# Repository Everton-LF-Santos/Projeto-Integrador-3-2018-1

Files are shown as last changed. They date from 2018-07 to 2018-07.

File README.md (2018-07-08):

<h1> Sistema de aquisição de sinais elétricos musculares microcontrolado </h1>

<p>Repositorio criado para a disciplina de Projeto Integrador 3, do curso de engenharia eletrônica do IFSC - câmpus Florianópolis. <br/>
</p>

<h2> Revisão Bibliográfica </h2>

<p> A revisão bibliográfica pode ser acessada na wiki deste projeto.</p>
<p> A seguir, links de uma apresentação e um relatório técnico elaborados para outra disciplina, mas em cima do mesmo projeto, que podem ajudar na compreensão.<p>

[Apresentação - EMG](https://github.com/Everton-LF-Santos/Projeto-Integrador-3-2018-1/blob/Eletroneuromiografia-ENMG/prototipo_e_testes/Apresenta%C3%A7%C3%A3o%20PI3%20-%20COm.pdf)

[Relatório Técnico -EMG](https://docs.google.com/document/d/1B7dxLtk4YTgo0cG7-Vo4bE_Du3ThqNgDaQOGe45rIPg/edit)

<h2> Diagrama de blocos </h2>

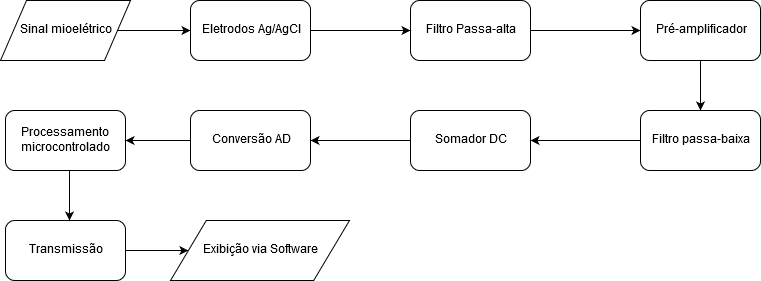
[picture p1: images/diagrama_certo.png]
Figura 1 - Diagrama de blocos do projeto Diagrama de Blocos


<h2> Pré-amplificador e filtro passa-alta </h2>
<p> Com a leitura das referências bilbiográficas da área feita e o diagrama de blocos definido, iniciou-se o desenvolvimento do projeto com o circuito de pré-amplificação. Foi encontrada no livro The Biomedical Engineering Book, uma topologia que junta o pré-amplificador e o filtro passa-alta no mesmo circuito. No exemplo da topologia, coincidentemente foi usado o INA118, mesmo amplificador de instrumentação disponível para o projeto. Na imagem a seguir, temos o esquemático simplificado e definição do ganho do componente.<p>
  
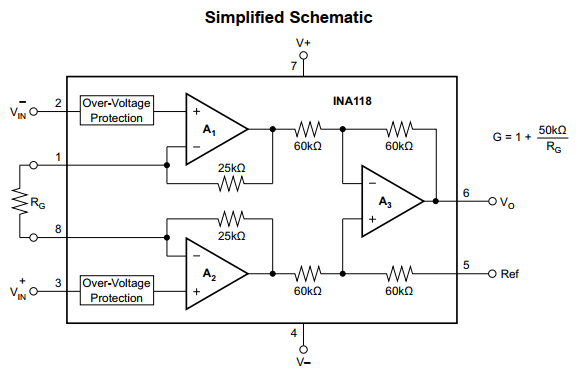
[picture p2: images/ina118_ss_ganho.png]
Figura 2 - esquematico e ganho INA118 Esquemático simples e ganho INA118
 

<p>Foi arbitrado um ganho de 51 para a estrutura, por resultar em um valor de 1kohm para Rg, fácil de obter, e por ser um valor na faixa aceitável de ganho para esse tipo de estrutura neste tipo de aplicação, segundo a bibliografia estudada. A frequência de corte do passa-alta foi definida como 25 Hz, pois abaixo desse valor há ruídos de movimentação mecânica, e os diagramas de energia observados nas referências mostra a concentração de energia do sinal para a faixa acima deste valor.<p>
  
<p>Todas as considerações feitas, os cálculos e simulações pertinentes foram executados. Os arquivos de ambas etapas citadas estão disponível no link.<p>
  
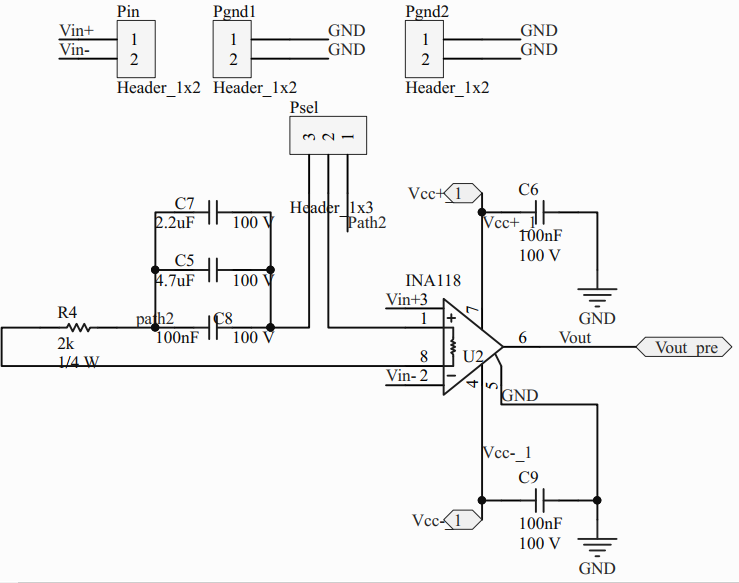
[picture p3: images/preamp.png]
Figura 3 - Circuito projetado Circuito projetado


[Calculos e Simulacoes - Pre_amp e PA](https://github.com/Everton-LF-Santos/Projeto-Integrador-3-2018-1/tree/Eletroneuromiografia-ENMG/pre_amp_e_passa_alta)

<h2> Filtro passa-baixa </h2>

<p>Com o primeiro bloco projetado, passou-se para o próximo bloco, o filtro passa-baixa. A topologia escolhida foi o filtro ativo Multiple Feedback com aproximação Butterworth. O ganho foi escolhido para 12,5 com o intuito de deixar o ganho em cascata da estrutura na casa das unidades de centenas. A frequência de corte de 250 Hz foi escolhida baseada no estudo dos diagramas de frequência do sinal  EMG. O ampop escolhido para implementar o circuito deste bloco foi o LM324, por atender as especificações de ganho e frequência e ser um componente de fácil obtenção e barato. Com os parâmetros do bloco definidos, passou-se então para os cálculos de componentes e simulações. Os arquivos pertinentes podem ser encontrados no link a seguir.<p>
  
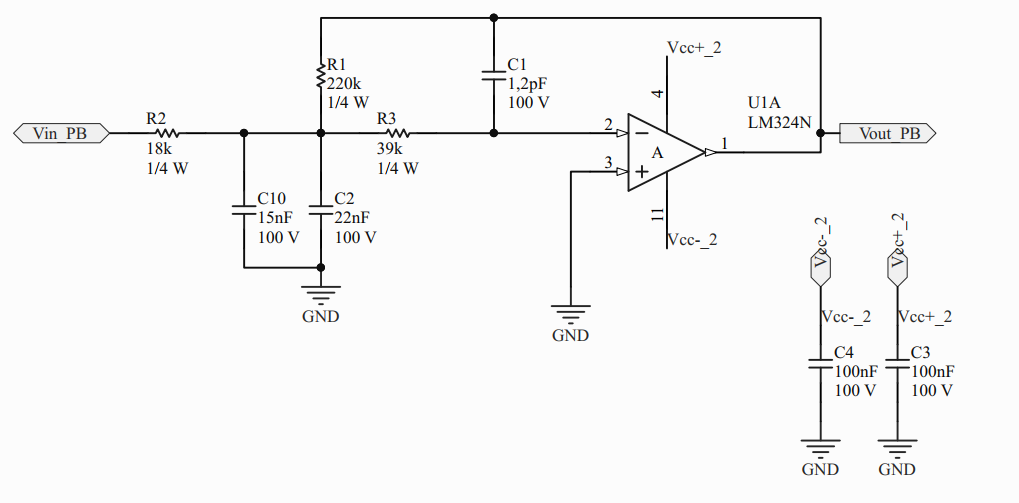
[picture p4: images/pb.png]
Figura 4 - Circuito projetado Circuito projetado

  
[Calculos e Simulacoes - Filtro Passa-Baixa](https://github.com/Everton-LF-Santos/Projeto-Integrador-3-2018-1/tree/Eletroneuromiografia-ENMG/passa_baixa)

<h2> Somador DC </h2>

<p> A faixa de variação da amplitude do sinal elétrico muscular pode ser consideralmente ampla, devido fatores como tipo e qualidade dos eletrodos, grupo muscular em análise, capacidade e fisiologia do individuo em análise, entre outros. Levando isso em consideração, foi desenvolvido um bloco de ajuste de ganho, para que seja possível adequar o sinal adquirido da melhor forma possível.
<p>Porém, para fazer uma adequação correta, deve se conhecerou onde se está, e onde se quer chegar. O que temos são sinais da ordem de centenas de microvolts a unidades de milivolts. O que queremos é um sinal de saída analógico que pode ser convertido para informação digital, de preferência em um microncontrolador de baixo consumo. Estes geralmente trabalham com alimentação em 3.3 V. Logo, podemos definir que queremos um sinal de saída do módulo de aquisição que seja de 0 V a 3.3V, correspondente a sinais mioelétricos captados pelo eletrodo da ordem de 250uV até 5mV.
<p> Tendo o ponto de partida e de chegada, podemos focar esforços na construção do caminho. Para termos um sinal totalmente positivo na saída, é necessário que seja feito um offset DC no sinal. Para isso, foi escolhida a topologia de amplificador operacional na configuração não-inversora. Os valores de resistência do circuito foram arbitrados para não ter influencia no casamento de impedância dos blocos. A tensão de referência deste circuito (que deve ser metade da excursão do sinal de saída, logo, 3.3/2 = 1,65 V) será provida por um seguidor de tensão. Como o seguidor inverte a polaridade da tensão, o valor de -1,65V necessário é pego de um divisor resistivo entre o GND e o -5V da alimentação simétrica dos ampops.
<p> Tendo definido os parâmetros necessários, passaram-se para os demais cálculos e simulações do bloco de offset DC. Os arquivos relacionados a esta etapa podem ser encontrados no link.
  
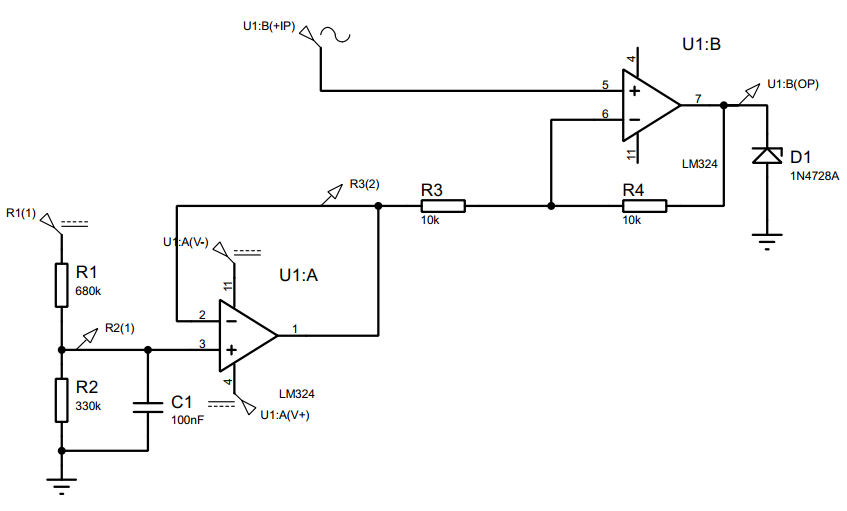
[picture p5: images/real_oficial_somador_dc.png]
Figura 5 - Circuito projetado Circuito projetado

  
[Calculos e Simulacoes - Somador DC](https://github.com/Everton-LF-Santos/Projeto-Integrador-3-2018-1/tree/Eletroneuromiografia-ENMG/somadorDC)

<h2> Ajuste de Ganho </h2>

<p> Devido a configuração e valores utilizados no bloco de offset DC, o sinal de entrada deste bloco deve variar de -0,815 V a +0,815 V para que haja 0 a 3.3V na saída. Com este faixa de amplitude necessária na entrada do bloco de offset, juntamente com a faixa de amplitude do sinal mioelétrico que deseja ser captada e conhecendo o ganho dos blocos anteriores, é possível finalmente projetar o bloco de ajuste de ganho. A topologia utilizada é simples, um amplificador operacional em configuração de ganho ajustável, com um trimpot conectado ao terminal inversor e na malha de realimentação e um diodo zener de 3.3V na saída para certificar que o valor máximo não seja ultrapassado. De acordo com os cálculos feitos, que podem ser observados nos arquivos desta etapa no link abaixo, o bloco de ajuste deve variar o ganho de aproximadamente 0,25 a 5. Conhecendo as impedâncias de entrada e saída dos blocos anteriores e posteriores, foram calculados os componentes necessários para que não houvesse influência na resposta em frequência do circuito. 
  
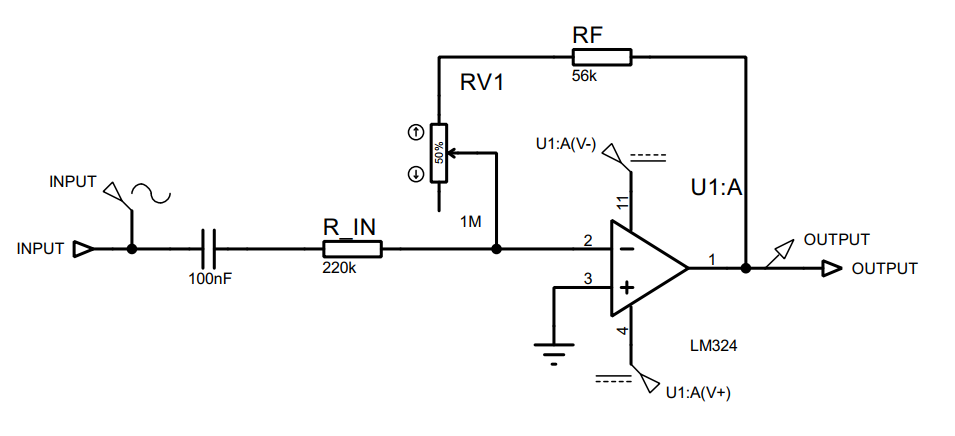
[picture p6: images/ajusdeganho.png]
Figura 6 - Circuito projetado Circuito projetado

  
[Calculos e Simulacoes - Ajuste de ganho](https://github.com/Everton-LF-Santos/Projeto-Integrador-3-2018-1/tree/Eletroneuromiografia-ENMG/ajuste_ganho)
  
<h2> Prótotipo de aquisição e testes </h2>

<p> Com os quatro bloco de hardware de aquisição prontos, foi feito um protótipo para validar o funcionamento dos circuitos escolhidos. O esquemático e layout elaborados no software Altium Designer foram feitos em blocos, para garantir a validação individual de cada um, antes do teste coletivo. É possível acoplar os blocos por meio de jumpers. Após confeccionada a placa, foram feitos os testes pertinentes. Os resultados estão na apresentação de slides do link a seguir. Os outros arquivos relacionados à etapa de prototipagem e testes também podem ser encontrados no link.
  
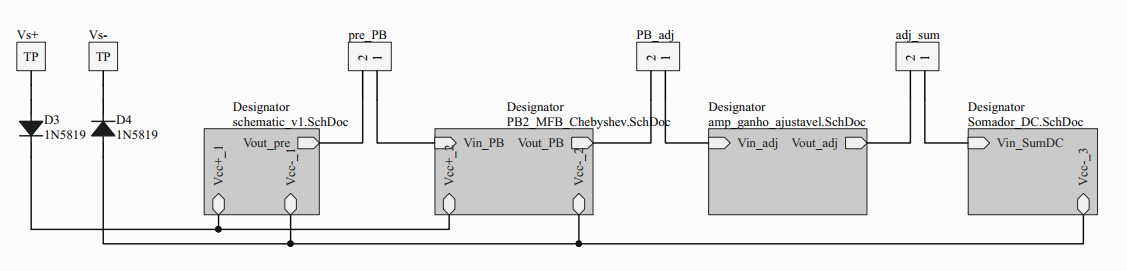
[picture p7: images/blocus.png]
Figura 7 - Blocos de hardware Blocos de hardware


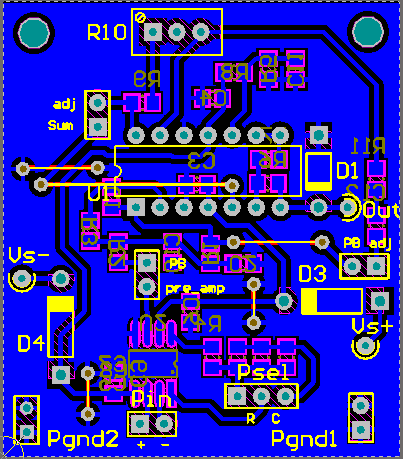
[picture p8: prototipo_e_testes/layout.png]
Figura 8 - layout layout


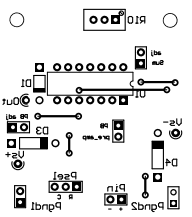
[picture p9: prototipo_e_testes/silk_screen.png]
Figura 9 - silk screen silk screen


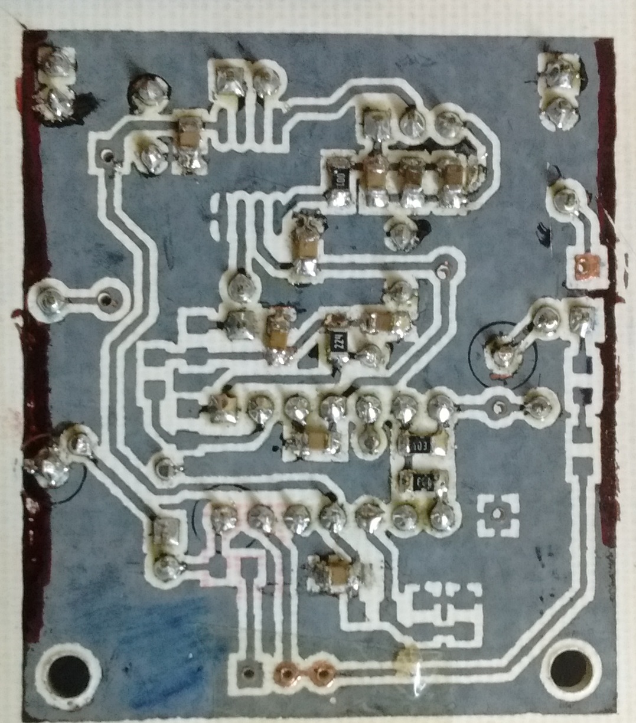
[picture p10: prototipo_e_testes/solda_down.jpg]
Figura 10 - soldas SMD soldas SMD

  
[Protótipo  e teste do hardware de aquisição](https://github.com/Everton-LF-Santos/Projeto-Integrador-3-2018-1/tree/Eletroneuromiografia-ENMG/prototipo_e_testes)

<h2> Isolamento da rede e regulação de tensão </h2>

Com os resultados dos testes, foi concluído que os blocos do hardware de aquisição estavam de acordo com os requisitos necessários, porém para próxima etapa (teste IN VIVO), seria necessário que o circuito fosse alimentado de forma independente da rede elétrica. Assim, foi desenvolvida uma placa de regulação de tensão para alimentar o prototipo a partir de baterias 9 V. Os arquivos do projeto estão disponiveis no link a seguir.

[Placa de regulação de tensão](https://github.com/Everton-LF-Santos/Projeto-Integrador-3-2018-1/tree/Eletroneuromiografia-ENMG/reg_tensao)

<h2> Teste In Vivo </h2>

Com a alimentação regulada das baterias e sem interferência conduzida da rede elétrica, foi feito o teste In Vivo do hardware de aquisição. Usando eletrodos de Prata/Cloreto de Prata com gel condutor e cabos blindados, foi feita leitura do sinal da musculatura do antebraço esquerdo. O sinal foi observado por meio do osciloscópio portátil Rohde & Schwarz modelo RTH1004. Os arquivos relacionados a etapa de teste in vivo pode ser acessados pelo link a seguir.

[Teste In Vivo](https://github.com/Everton-LF-Santos/Projeto-Integrador-3-2018-1/tree/Eletroneuromiografia-ENMG/teste_vivo)

<h2> Teste In Vivo com transmissão dos dados </h2>

Por fim, foi iniciada a etapa de conversão analógica-digital transmissão dos dados, por meio do uso de um microcontrolador. Foi escolhido o chip ATMEGA328P pela experiência com desenvolvimentos anteriores. O código desenvolvido faz a conversão do sinal analógico em digital e envia o dado por meio do módulo Bluetooth HC-06. Para fins de facilitação de código, foi usada resolução de 8 bits na conversão A/D, com taxa de amostragem de 1 kHz. O uso de transmissão de dados sem fio é para garantir o isolamento galvânico do circuito de aquisição de qualquer outro equipamento eletrônico. Para visualização dos dados foi usado o software SerialPlot. Os arquivos relacionados a etapa de desenvolvimento do firmware, aquisição e visualização dos dados podem ser acessados no link a seguir.

[Teste In Vivo com aquisição de dados via Bluetooth](https://github.com/Everton-LF-Santos/Projeto-Integrador-3-2018-1/tree/Eletroneuromiografia-ENMG/firmware_bt)

<h2> Referências Bibliográficas </h2>

[link para arquivos das referências bibliográficas](https://drive.google.com/drive/u/1/folders/12AXk9AZwwBUo14S7_4OgoAu70kQn8SUb?ogsrc=32)

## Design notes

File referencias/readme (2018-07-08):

Pasta com pds das teses, livros e outros documentos utilizados como referência bibliográfica para este trabalho. 
[Pasta no Drive com os pdfs das referencias](https://drive.google.com/drive/u/1/folders/12AXk9AZwwBUo14S7_4OgoAu70kQn8SUb?ogsrc=32)

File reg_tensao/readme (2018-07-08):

Pasta com os arquivos relacionados ao bloco de regulação de tensão de alimentação das baterias.

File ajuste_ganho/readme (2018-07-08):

Pasta com arquivos relacionados ao bloco de ajuste de ganho.

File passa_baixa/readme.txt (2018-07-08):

Arquivos relacionados ao bloco de filtro ativo passa-baixa topologia multiple feedback com aproximação butterworth.

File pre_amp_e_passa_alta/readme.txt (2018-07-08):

Arquivos dos blocos de pré-amplificação e filtro passa-alta.

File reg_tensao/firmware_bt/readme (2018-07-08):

Pasta com arquivos relacionados as etapas de desenvolvimento de firmware, transmissao e visualizacao dos dados.

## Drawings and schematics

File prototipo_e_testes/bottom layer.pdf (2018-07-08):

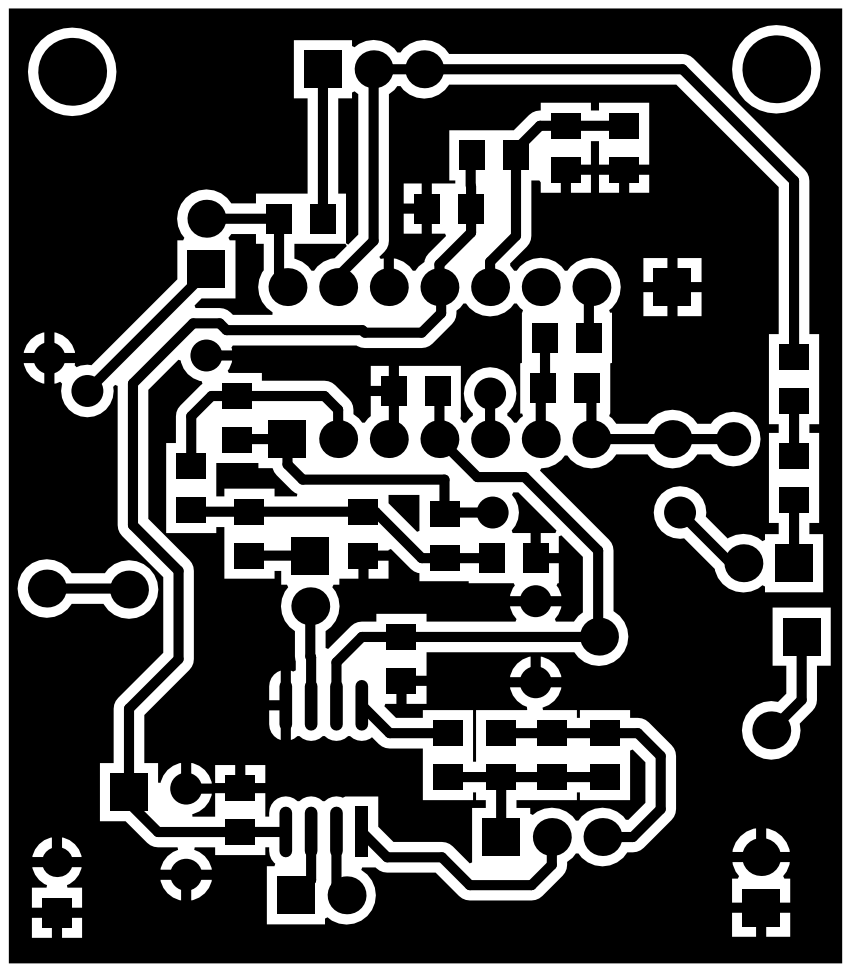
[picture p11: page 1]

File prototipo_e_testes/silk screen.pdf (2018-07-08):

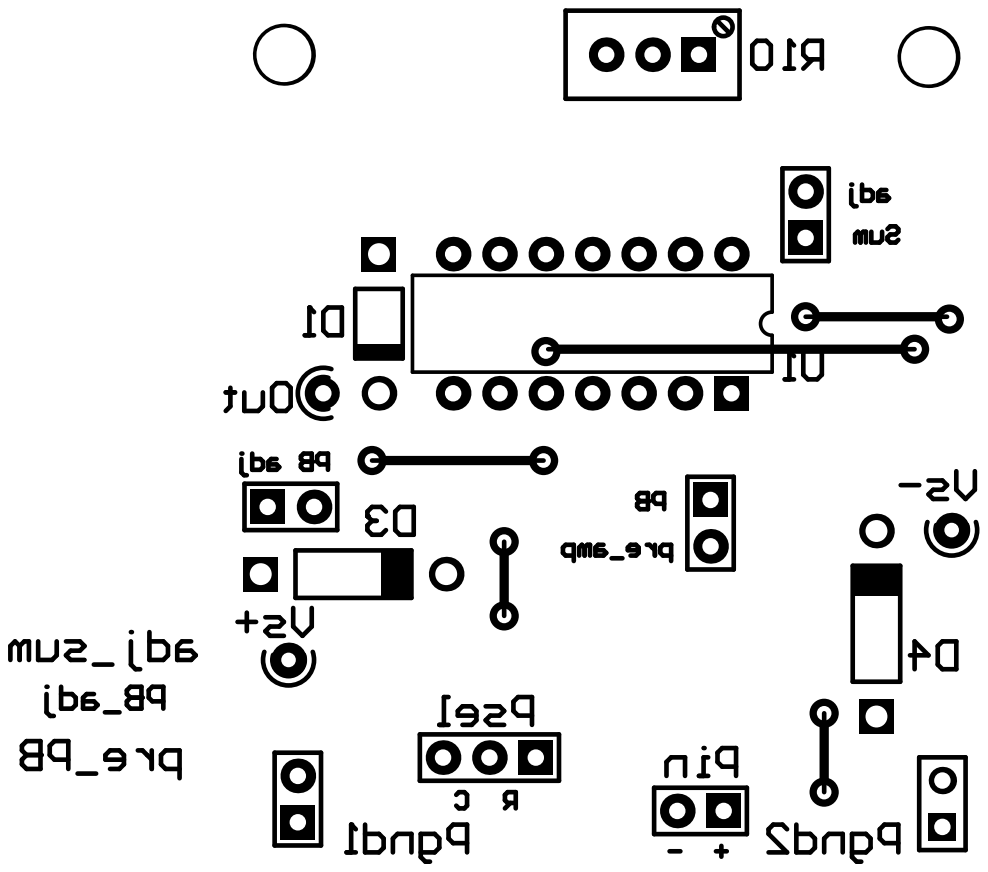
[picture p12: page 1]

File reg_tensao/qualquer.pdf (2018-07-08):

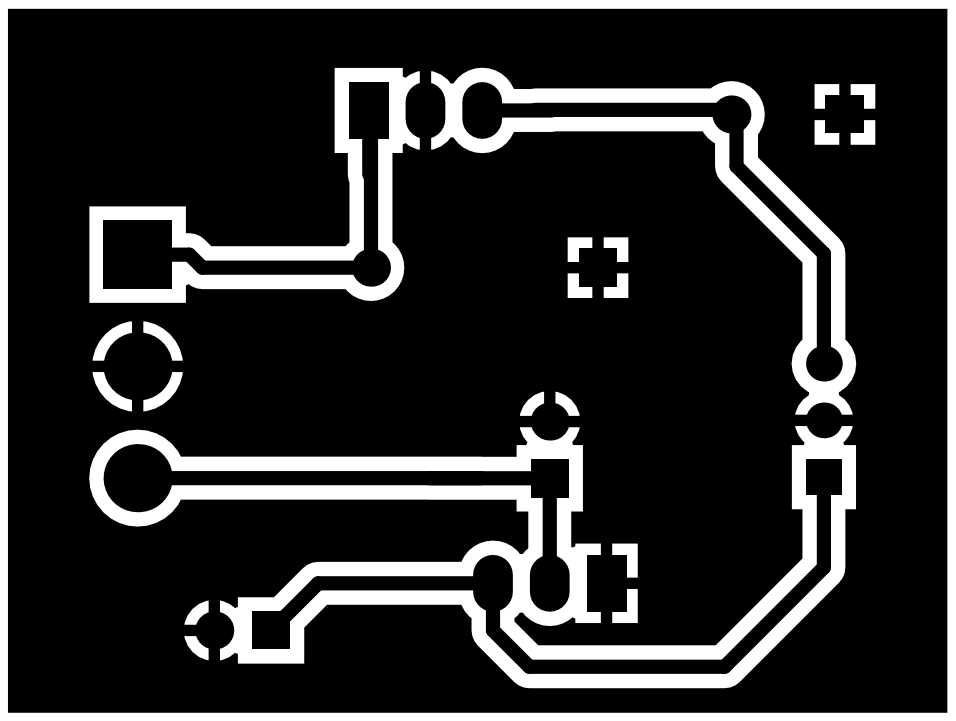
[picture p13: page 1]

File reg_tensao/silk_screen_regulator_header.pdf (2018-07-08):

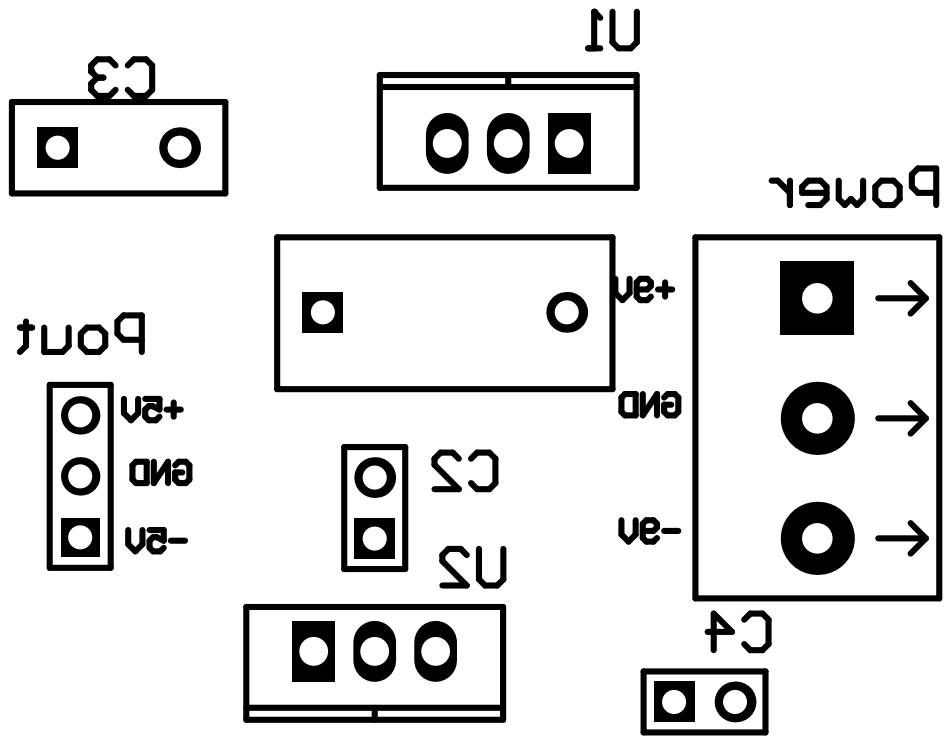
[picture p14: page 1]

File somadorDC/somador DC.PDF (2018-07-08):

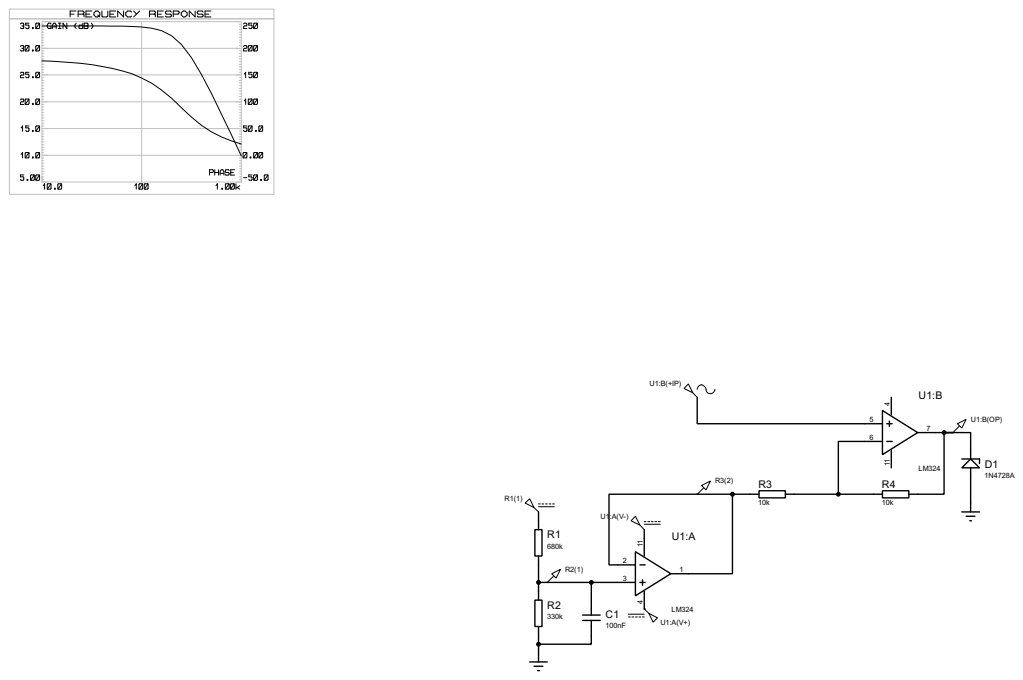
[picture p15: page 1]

FILE NAME:
DESIGN TITLE: somador DC.pdsprj

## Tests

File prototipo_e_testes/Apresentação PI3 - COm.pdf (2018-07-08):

# PROJETO INTEGRADOR III -MÓDULO DE AQUISIÇÃO DE SINAIS ELÉTRICOS MUSCULARES

Projeto IntegradorIII
Comunicação e Expressão
Augusto Daniel Rodrigues

## SUMÁRIO

- Sinais mioelétricos
- Condições de detecção de sinal
- Condicionamento de sinal
- Projeto dos blocos
- Esquemático, Layout e Hardware
- Testes dos blocos
- Referências

## SINAIS MIOELÉTRICOS

- Sinal sináptico -> axônio neuromotor -> potencial de ação;
- unidade motora;
- MUAP e MUAPT;
- Sinal EMG;

## SINAIS MIOELÉTRICOS

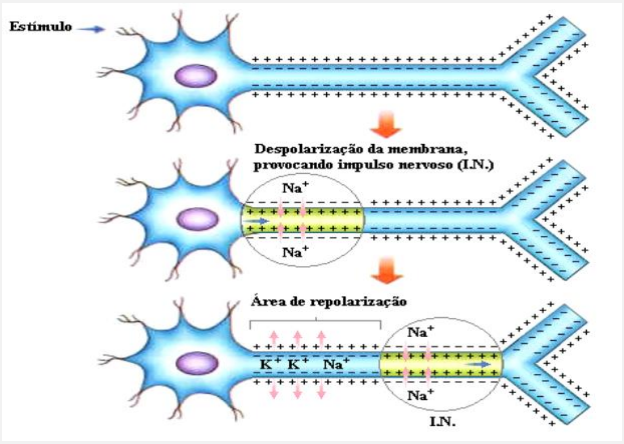
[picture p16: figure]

- Fonte:Vilela, 2004 apud Caparelli, 2007.

## SINAIS MIOELÉTRICOS

- Fonte:Vilela, 2004 apud Caparelli, 2007.

## SINAIS MIOELÉTRICOS

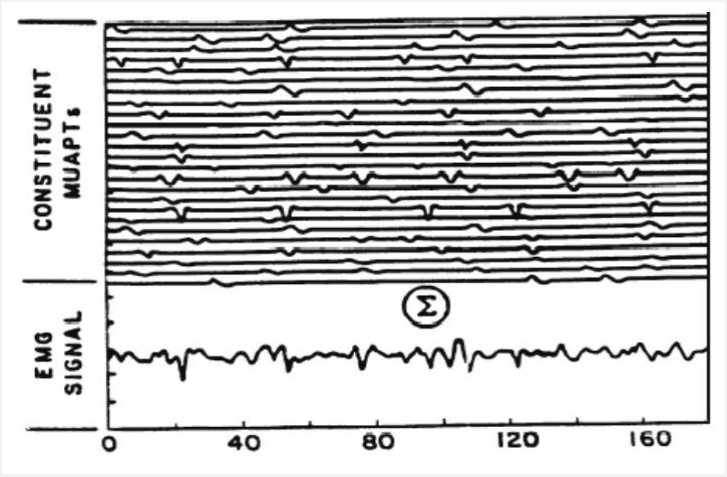
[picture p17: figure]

- Fonte: Basmajian; De Luca, 1985 apud Caparelli, 2007.

## CONDIÇÕES DE DETECÇÃO DO SINAL

- Eletrodos de agulha x eletrodos de superfície;
- Eletrodos passivos e ativos;
- 10mVpp e 10kHz x 5mVpp 250 Hz;
- Ruídos e interferências;
- Posicionamento dos eletrodos;
- Eletrodos de referência;
- Arranjos monopolar, bipolar, etc;

## CONDIÇÕES DE DETECÇÃO DO SINAL

- Ruídos e interferências;
- Cross Talk;
- Movimentos;
- EMI (rede elétrica);
- Componentes e técnicas de layout;

## SINAIS MIOELÉTRICOS

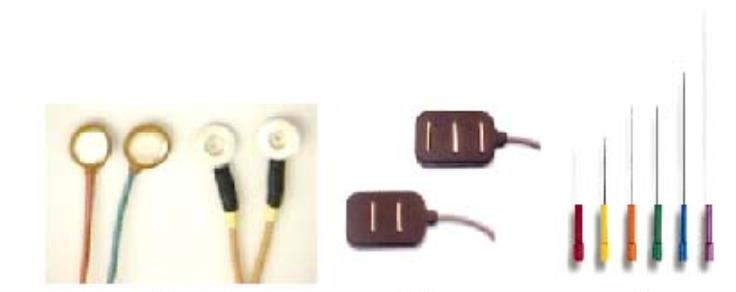
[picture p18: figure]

Fonte: Caparelli, 2007.

## SINAIS MIOELÉTRICOS

Fonte : https://www.primecirurgica.com.br/eletrodo-universal-red-dot-pct-c-50-unds-2570-3m-p760/

## SINAIS MIOELÉTRICOS

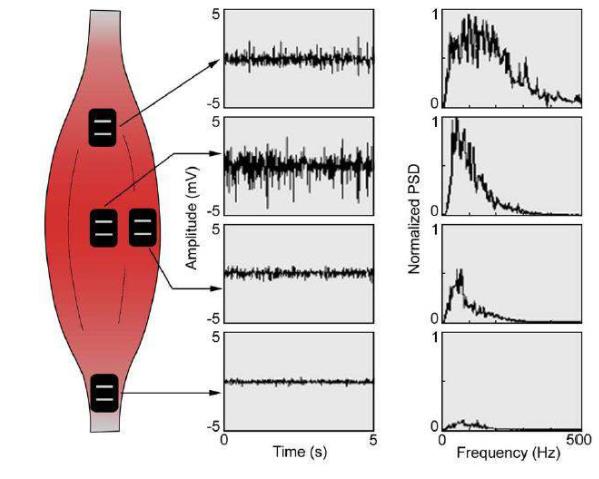
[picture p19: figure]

Fonte: Caparelli, 2007.

## CONDICIONAMENTO DO SINAL

- Amplificação do sinal;
- Filtragem em frequência;
- Offset DC;
- Conversão Analógica-Digital;
- Processamento;
- Visualização;

## CONDICIONAMENTO DO SINAL

- Amplificação do sinal;
- Amplificador de Instrumentação
- Amplificação diferencial;
- Alto CMRR;
- Ganho linear de até milhares de vezes;
- Alta impedância de entrada;

## CONDICIONAMENTO DO SINAL

Fonte: FRANCO, 1998 apud PEPINO, 2007.

## CONDICIONAMENTO DO SINAL

- Filtragem do sinal
- Anulação ou permissão do prosseguimento de um sinal em função de sua frequência;

## CONDICIONAMENTO DO SINAL

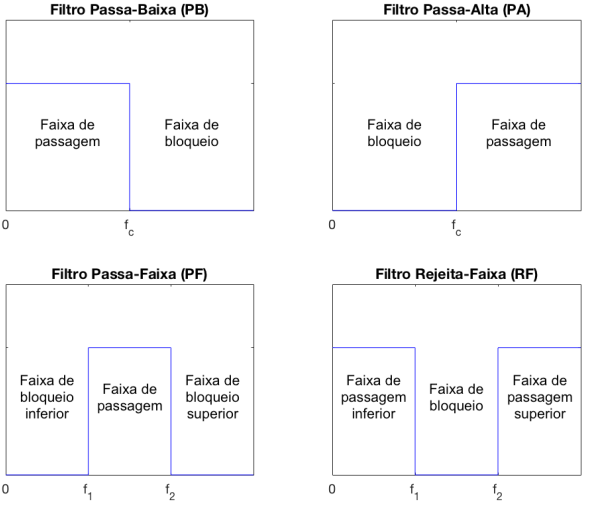
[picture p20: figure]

Fonte: LIMOLI (2017, p. 37).

## CONDICIONAMENTO DO SINAL

- Offset DC
- Elevação do nível de tensão do sinal;
- Sinal contínuo;
- Intervalo totalmente positivo (>=0);

## CONDICIONAMENTO DO SINAL

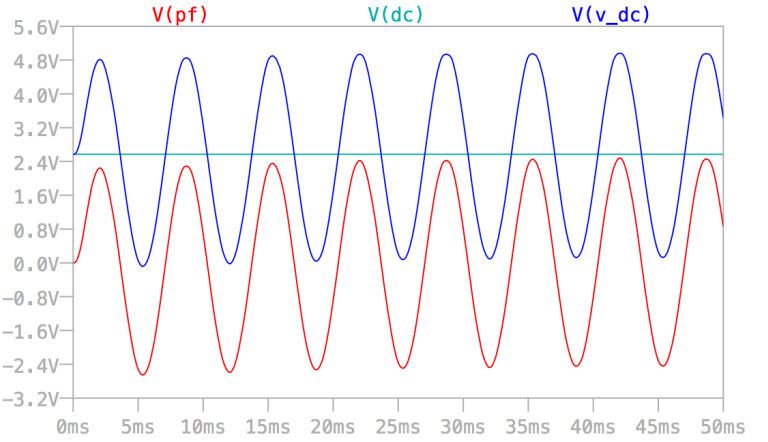
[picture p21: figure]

Fonte: LIMOLI (2017, p. 57).

## CONDICIONAMENTO DO SINAL

- Conversão Analógica-Digital
- Conversão de um nível de tensão para um conjunto de bits;
- Janela de conversão (1.1 V, 3.3 V, 5 V);
- Resolução da Conversão (nº de bits);
- Taxa de amostragem;

## CONDICIONAMENTO DO SINAL

Fonte: https://www.globalspec.com/learnmore/data_acquisition_signal_conditioning/signal_converting/analog_to_digital_converters

## PROJETO DOS BLOCOS

- Pré-requisitos / Parâmetros de projeto
- Conversão AD de 3.3 V 10 bits;
- Offset DC de 1,65 V;
- Janela de frequência de 25 Hz a 250 Hz;
- Considerar sinais da ordem de |250uV| à |5mV|;
- Ampop de instrumentação disponível = INA118;
- Ampop para demais circuitos = LM324N;
- Alimentação simétrica |5V| ( regulada de baterias de 9 V);

## PRÉ-AMPLIFICADOR + PASSA-ALTA

G = 51,
logo Rg = 1kΩ;

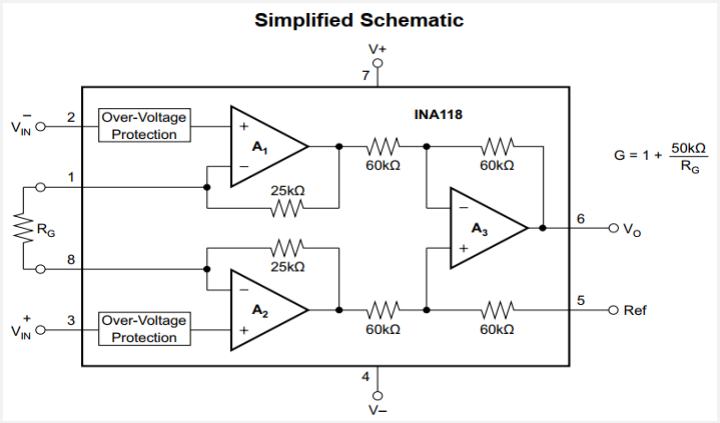
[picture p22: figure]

Fonte : Datasheet INA118. Disponível em : http://www.ti.com/lit/ds/symlink/ina118.pdf.

## PRÉ-AMPLIFICADOR + PASSA-ALTA

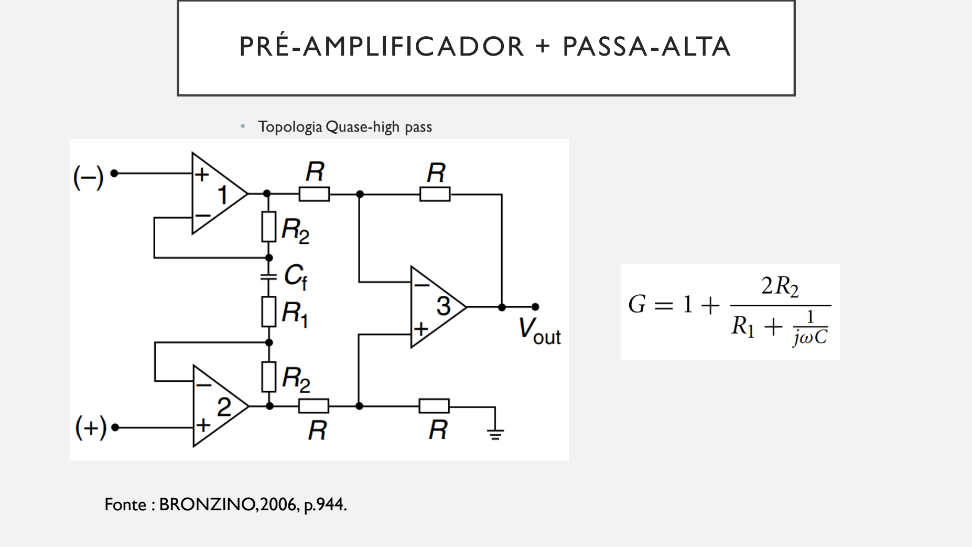
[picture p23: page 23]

- Topologia Quase-high pass

Fonte : BRONZINO, 2006, p.944.

## PRÉ-AMPLIFICADOR + PASSA-ALTA

Fonte: Do autor.

## PRÉ-AMPLIFICADOR + PASSA-ALTA

- Ganho = 51;
- Frequência de corte inferior = 25 Hz;
- C = 7 uF;

PRÉ -AMPLIFICADOR
+ PASSA-ALTA

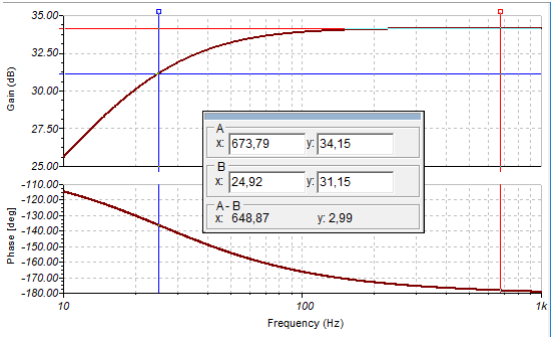
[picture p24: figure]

- Simulação
- 34,15 = 20*log(51)
- 31,15 = 20*log(51/√2)
- -3 dB;

Fonte: Do autor.

## PASSA-BAIXA

- Ganho = 12,5;
- Filtro ativo de 2ª ordem Multiple Feedback com aproximação Butterworth;
- Frequência de corte superior = 250 Hz;

## PASSA-BAIXA

Fonte: PERTENCE JR, Antônio (2003, p.184).

## PASSA-BAIXA

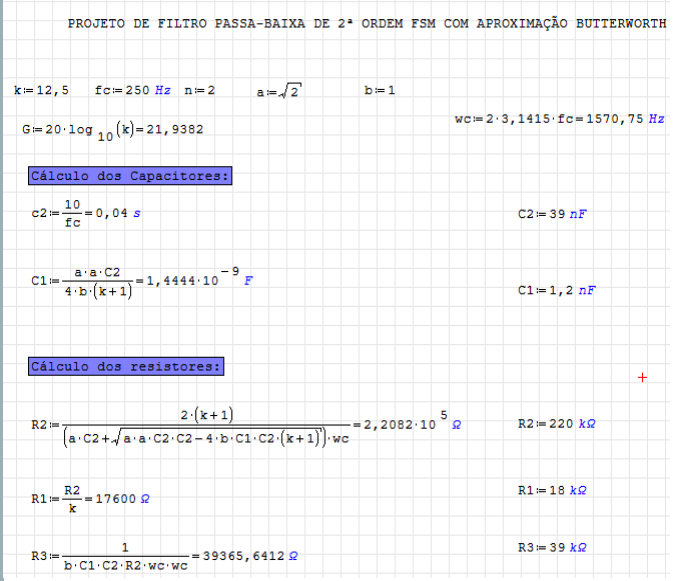
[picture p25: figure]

Fonte: Do autor.


## PASSA-BAIXA

- Simulação:
- Gs=10^(23,32/20) = 14,65
- Nova fc = 220 Hz (OK!)
- Ampop LM324N;

Fonte: Do autor.

## SOMADOR DC

- Saída de 0V a 3.3V;
- Buffer + somador não inversor;
- Capacitor de estabilização;
- Vref = 1,65V;
- Vout = 2*Vin +Vref, logo
- –0,815V <Vin < +0,815V
- Ampop LM324N;

Fonte: Do autor.

## SOMADOR DC

- Vref = -Vcc * R2 / (R1 + R2);
- R1 = 2,03*R2;
- R1 = 680k e R2 = 330k, Vref = 1,63 V;


Fonte: Do autor.

## AJUSTE DE GANHO

- Ganho do primeiro bloco = 51;
- Ganho do primeiro bloco = 12,5;
- Ganho em cascata = 637,5;
- Ganho máximo:
- |250uV| * 637,5 = 0,159375;
- 0,815 / 0,159375 = 5,11;
- Ganho mínimo:
- |5mV| * 637,5 = 3,1875;
- 0,815 / 3,1875 = 0,256;

## AJUSTE DE GANHO


- Capacitor de acoplamento AC;
- Situação 1:
- 56k/220k = 0,254;
- Situação 2:
- 1056k/220k = 4,8;

Fonte: Do autor.

## ESQUEMÁTICO, LAYOUT E HARDWARE

Fonte: Do autor.

## ESQUEMÁTICO, LAYOUT E HARDWARE


Fonte: Do autor.

## ESQUEMÁTICO, LAYOUT E HARDWARE


## ESQUEMÁTICO, LAYOUT E HARDWARE

Fonte: Do autor.

## ESQUEMÁTICO, LAYOUT E HARDWARE


Fonte: Do autor.

## ESQUEMÁTICO, LAYOUT E HARDWARE

Fonte: Do autor. | Fonte: Do autor. | Fonte: Do autor.

## ESQUEMÁTICO, LAYOUT E HARDWARE


Fonte: Do autor. | Fonte: Do autor.

## TESTES DOS BLOCOS


- Pré-amplificador + passa-alta:
- 3,68 / 77,6e-3 = 47,42;
- 500 Hz;
Fonte: Do autor. | Fonte: Do autor.

## TESTES DOS BLOCOS


- Pré-amplificador + passa-alta:
- 2,48 / 77,6e-3 = 31,96 ~= 47,42*0,707;
- ~27 Hz;
Fonte: Do autor. | Fonte: Do autor.

## TESTES DOS BLOCOS


- Passa-Baixa:
- 3,56/ 0,320 = 11,125;
- ~100 Hz;
Fonte: Do autor. | Fonte: Do autor.

## TESTES DOS BLOCOS

- Passa-Baixa:
- 3,72/ 0,316 = 11,77;
- ~27 Hz;


Fonte: Do autor.

## TESTES DOS BLOCOS

- Passa-Baixa:
- 2,60/ 0,318 = 8,17 ~= 11,77*0,707;
- ~250 Hz;

Fonte: Do autor.

## TESTES DOS BLOCOS

- Ajuste de Ganho:
- 2,90/ 0,624 = 4,64;


- ~150 Hz; | Fonte: Do autor.

## TESTES DOS BLOCOS

- Ajuste de Ganho:
- 0,556 / 2,06 = 0,269;


- ~150 Hz; | Fonte: Do autor.

## TESTES DOS BLOCOS


- Somador DC:
Fonte: Do autor. | Fonte: Do autor.

## OBRIGADO!

Augusto Daniel Rodrigues

augusto.dr@aluno.ifsc.edu.br

## REFERÊNCIAS

BRONZINO, Joseph D. The Biomedical Engineering Handbook: Medical Devices and Systems. 3th ed. Hartford. Taylor and Francis, 2006.
Disponível em:https://brainmaster.com/software/pubs/brain/The_Biomedical_Engineering_Handbook_.pdf

CAPARELLI, Thiago B. Projeto e desenvolvimento de um sistema multicanal de biotelemetria para detecção de sinais ECG, EEG e EMG. 2007. 109 p. Dissertação (Pós-graduação em Engenharia Elétrica) - Faculdade de Engenharia Elétrica, Universidade Federal de Uberlândia, Uberlândia.
Disponível em:https://repositorio.ufu.br/handle/123456789/14636

DE LUCA, Carlo J; BASMAJIAN, John V. Muscles Alive: Their functions revealed by eletromyography. 5th ed. Baltimore: Willians andWilkins, 1985.

LIMOLI, Camila S. Protótipo de um eletromiógrafo sem fio de baixo custo. 2017. 75 p. Trabalho de Conclusão de Curso (Graduação no Curso de Engenharia Elétrica com Ênfase em Eletrônica) - Escola de Engenharia de São Carlos, Universidade de São Paulo. - São Carlos.
Disponível em : http://www.tcc.sc.usp.br/tce/disponiveis/18/180450/tce-29052017-162649/?&lang=br

## REFERÊNCIAS

PEPINO, André L.G. Sistema de controle de Dispositivos Através de EMG(Eletromiografia). 2007. 90p. Monografia de Conclusão de Curso (Graduação em Engenharia da Computação) - Núcleo de Ciências Exatas e Tecnológicas, Centro Universitário Positivo. Curitiba.
Disponível em:https://www.up.edu.br/blogs/engenharia-da-computacao/wp-content/.../2007.1.pdf

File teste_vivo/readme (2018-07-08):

Pasta com arquivos relacionados ao teste in vivo com transmissao dos dados adquiridos para o PC via Bluetooth.

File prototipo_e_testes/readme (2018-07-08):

Pasta com os arquivos relacionados ao protótipo do hardware de aquisição e o testes dos blocos do protótipo.

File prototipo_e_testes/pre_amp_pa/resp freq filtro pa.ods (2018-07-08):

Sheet: teste 1 - filtro pa + preamp
f | Vin | Vout | G
1.000000 | 0,202 | 0,32 | 1,58415841584158
1.300000 | 0,198 | 0,32 | 1,61616161616162
1.690000 | 0,19 | 0,48 | 2,52631578947368
2.197000 | 0,22 | 0,48 | 2,18181818181818
2.856100 | 0,182 | 0,48 | 2,63736263736264
3.712930 | 0,178 | 0,72 | 4,04494382022472
4.826809 | 0,184 | 0,64 | 3,47826086956522
6.274852 | 0,186 | 0,8 | 4,30107526881721
8.157308 | 0,202 | 0,96 | 4,75247524752475
10.604500 | 0,206 | 1,12 | 5,4368932038835
13.785850 | 0,228 | 1,44 | 6,31578947368421
17.921604 | 0,22 | 1,6 | 7,27272727272727
23.298086 | 0,204 | 1,92 | 9,41176470588235
30.287512 | 0,216 | 2,08 | 9,62962962962963
39.373764 | 0,204 | 2,24 | 10,9803921568627
51.185894 | 0,214 | 2,48 | 11,588785046729
66.541664 | 0,212 | 2,56 | 12,0754716981132
86.504166 | 0,202 | 2,72 | 13,4653465346535
112.455414 | 0,224 | 2,78 | 12,4107142857143
146.192032 | 0,212 | 2,7 | 12,7358490566038
190.049637 | 0,198 | 2,8 | 14,1414141414141
247.064529 | 0,202 | 2,8 | 13,8613861386139
321.183899 | 0,204 | 2,88 | 14,1176470588235
417.539063 | 0,21 | 2,88 | 13,7142857142857
542.800781 | 0,194 | 2,88 | 14,8453608247423
705.640991 | 0,23 | 2,88 | 12,5217391304348
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

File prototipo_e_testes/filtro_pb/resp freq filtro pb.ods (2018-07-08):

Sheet: teste 1 - filtro pb
f | Vin | Vout | G
1.000000 | 0,152 | 0,58 | 3,82
1.300000 | 0,152 | 0,62 | 4,08
1.690000 | 0,148 | 0,68 | 4,59
2.197000 | 0,148 | 0,66 | 4,46
2.856100 | 0,154 | 0,68 | 4,42
3.712930 | 0,152 | 0,7 | 4,61
4.826809 | 0,158 | 0,72 | 4,56
6.274852 | 0,156 | 0,68 | 4,36
8.157308 | 0,154 | 0,68 | 4,42
10.604500 | 0,166 | 0,68 | 4,10
13.785850 | 0,168 | 0,7 | 4,17
17.921604 | 0,168 | 0,68 | 4,05
23.298086 | 0,148 | 0,7 | 4,73
30.287512 | 0,148 | 0,7 | 4,73
39.373764 | 0,15 | 0,68 | 4,53
51.185894 | 0,16 | 0,7 | 4,38
66.541664 | 0,17 | 0,7 | 4,12
86.504166 | 0,156 | 0,68 | 4,36
112.455414 | 0,15 | 0,66 | 4,40
146.192032 | 0,168 | 0,64 | 3,81
190.049637 | 0,164 | 0,6 | 3,66
247.064529 | 0,158 | 0,5 | 3,16
321.183899 | 0,158 | 0,44 | 2,78
417.539063 | 0,158 | 0,3 | 1,90
542.800781 | 0,182 | 0,24 | 1,32
705.640991 | 0,16 | 0,16 | 1,00
917.333313 | 0,172 | 0,14 | 0,81
1192.533325 | 0,16 | 0,1 | 0,63
1550.293335 | 0,154 | 0,1 | 0,65
2015.381348 | 0,168 | 0,1 | 0,60
2619.995850 | 0,148 | 0,1 | 0,68
3405.994629 | 0,16 | 0,1 | 0,63
4427.792969 | 0,168 | 0,07 | 0,42
5756.130859 | 0,156 | 0,1 | 0,64
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

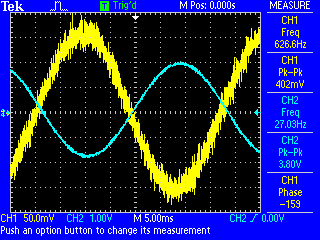
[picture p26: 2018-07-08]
prototipo_e_testes/filtro_pb/TEK0004.BMP

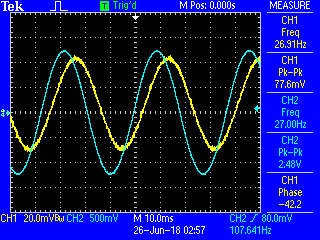
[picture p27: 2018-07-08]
prototipo_e_testes/pre_amp_pa/TEK0005.BMP

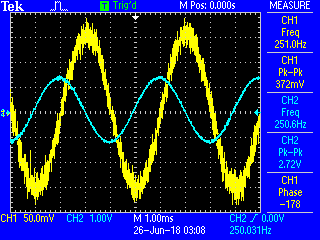
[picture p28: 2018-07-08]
prototipo_e_testes/filtro_pb/TEK0007.BMP

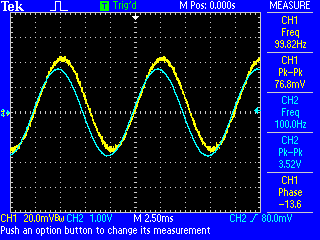
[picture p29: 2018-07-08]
prototipo_e_testes/pre_amp_pa/TEK0003.BMP

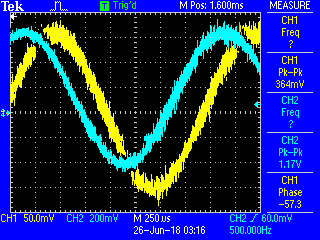
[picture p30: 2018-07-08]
prototipo_e_testes/filtro_pb/TEK0010.BMP

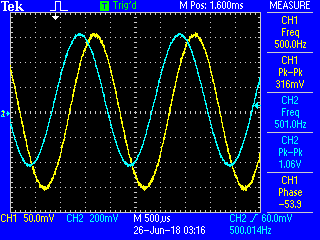
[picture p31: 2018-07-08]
prototipo_e_testes/filtro_pb/TEK0011.BMP

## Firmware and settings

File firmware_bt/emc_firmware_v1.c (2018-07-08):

/* -----------------------------------------------------------------------------
 * Project:     Project Name
 * File:        fileName.c
 * Author:      Project Author
 * Created:		2017-03-16
 * Modified:	2017-03-16
 * Version:     1.0
 * Purpose:     What this project does.
 * -------------------------------------------------------------------------- */

// -----------------------------------------------------------------------------
// System definitions ----------------------------------------------------------

#define F_CPU 16000000UL

// -----------------------------------------------------------------------------
// Header files ----------------------------------------------------------------

#include "globalDefines.h"
#include "ATmega328.h"


// -----------------------------------------------------------------------------
// Project definitions ---------------------------------------------------------

// -----------------------------------------------------------------------------
// New data types --------------------------------------------------------------
typedef union systemFlags_t{
	struct{
		uint8 update_Buffer	: 1;
		uint8 adc_Conv_Flag	: 1;
		uint8 unused_Bits	: 6;
	};
	uint8 allFlags;
} systemFlags_t;
// -----------------------------------------------------------------------------
// Function declaration --------------------------------------------------------

// -----------------------------------------------------------------------------
// Global variables ------------------------------------------------------------
volatile systemFlags_t systemFlags;
volatile uint8 emc_read = 0;
// -----------------------------------------------------------------------------
// Main function ---------------------------------------------------------------

int main(void)
{
	// INPUT/OUTPUT Config
	DDRB = 0x01;
	
	adcConfig(ADC_MODE_AUTO_TIMER1_COMPB, ADC_REFERENCE_POWER_SUPPLY, ADC_PRESCALER_OFF);
	adcDataPresentation(ADC_LEFT_ADJUSTED);
	adcSelectChannel(ADC_CHANNEL_0);
	adcDisableDigitalInput(ADC_CHANNEL_0);
	adcEnable();
	adcActivateInterrupt();
	
	
	// Usart Config
	usartConfig(USART_MODE_ASYNCHRONOUS, USART_BAUD_9600, USART_DATA_BITS_8, USART_PARITY_NONE, USART_STOP_BIT_SINGLE);
	usartActivateTransmissionCompleteInterrupt();
	usartEnableTransmitter();
	usartStdio();
	
	timer1Config(TIMER_B_MODE_CTC, TIMER_A_PRESCALER_OFF);
	timer1SetCompareAValue(14746);
	
	// Variable declaration
	uint8_t bt_buffer[10];
	uint8 bf_index = 0;
	
	// Variable initialization
	systemFlags.adc_Conv_Flag = 0;
	systemFlags.update_Buffer = 0;
	
	// Enable Global Interrupts
	sei();

	while(1)
	{
		if(systemFlags.update_Buffer)
		{
			//usartTransmit(emc_read);
			printf("%d\n", emc_read);
			systemFlags.update_Buffer = 0;
		}		
	}

	return 0;
}

// -----------------------------------------------------------------------------
// Interruption handlers -------------------------------------------------------

ISR(ADC_vect)
{
	cplBit(PORTB, 0);
	emc_read = ADCH;
	systemFlags.update_Buffer = 1;
	timer1ClearCompareBInterruptRequest();
}
// -----------------------------------------------------------------------------

// Function definitions --------------------------------------------------------

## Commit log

2018-04-22 adição da pasta de imagens da documentação ao repositório
2018-04-22 Adição do segundo estilo de inserção de imagem
2018-04-22 tentativa 3 de colocar imagem
    Acho que coloquei o caminho para a imagem correto agora.
2018-04-22 Tentativa 4 de inserir imagem
    Nome e extensão do arquivo estavam errados.
    capturar5.jgp -> Capturar.PNG
2018-04-22 Tentativa 5 de inserir imagem
    Nome, extensão e caminho do arquivo finalmente corretos.
    https://github.com/Everton-LF-Santos/Projeto-Integrador-3-2018-1/blob/Eletroneuromiografia-ENMG/images/Capturar5.PNG
2018-04-22 Transf. dos textos pra wiki
    Foi transferido para a wiki do projeto todo o material referente a revisão bibliográfica do tema.
2018-04-22 imagem de muapt e diagrama de blocos
2018-07-08 Imagens faltantes para a revisao bibliografica
2018-07-08 adicionada imagem de espectro de potencia
2018-07-08 criação da pasta do bloco de preamp e pa
2018-07-08 schematics and calculations preamp and pa
    [schematic_v1.SchDoc]
2018-07-08 add link para pasta do pre_amp e pa
2018-07-08 addos arquivos do bloco passa-baixa
    [PB2_MFB_Butterworth.SchDoc]
2018-07-08 addos arquivos bloco somadorDC
    [Somador_DC.SchDoc]
2018-07-08 criacao da pasta do bloco ajuste de ganho
2018-07-08 addos arquivos bloco ajuste de ganho
    [amp_ganho_ajustavel.SchDoc]
2018-07-08 add calculo de impedancias somaDC
2018-07-08 add calculo de impedancias ajuste de ganho
2018-07-08 addos links + texto
    links das pastas dos blocos de ajuste de ganho e somador DC e texto da etapa de prototipo e teste do hardware de aquisição.
2018-07-08 pasta de design do hardware e testes
2018-07-08 addos arquivos pcb e testes
    [PB2_MFB_Chebyshev.SchDoc, Somador_DC.SchDoc, amp_ganho_ajustavel.SchDoc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]
2018-07-08 criacao da pasta do bloco de regulaçao de tensao
2018-07-08 addo arquivos regulador de tensao
    [linear_reg_bat.PrjPcb, pcb_layout_v1.PcbDoc, reg_bats.SchDoc]
2018-07-08 add resposta frequencia pb
    [resp freq filtro pb.ods]
2018-07-08 add resposta em frequencia pa
    [resp freq filtro pa.ods]
2018-07-08 add de texto + links
    adição dos textos das etapas de regulação de tensão e microncontroladores e os respectivos link
2018-07-08 correcao do link da etapa de prototipo e testes
2018-07-08 adição de título nas etapas
2018-07-08 adicao de imagens
